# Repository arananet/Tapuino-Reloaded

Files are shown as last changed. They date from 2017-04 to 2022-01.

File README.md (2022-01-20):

# Tapuino-Reloaded

Designed in 2017 By @edu_arana in collaboration with @groovydrifter & @jgilcas. Based on the original schematic design of Peter Edwards.

# Updates

20/01/2021: Uploaded gerbers version 0.42 with the pin8 fixed on HC4050.

20/01/2021: On rev 0.41 There might be a problem with pin 8 on the SD card buffer. If PCB manufacturer does not populate a required via to make pin 8 from the HC4050 to GND, this could produce a problem with SD card detection. If you have a multimeter, try to measure pin 8 from the HC4050 to GND, if you have continuity then the SD Card detection or initialization problem might be elsewhere, if not, to fix this, try to solder pin 8 to pin 2 of the octocoupler (GND). Find the instruction on how to fix this on the GERBERS-NANO directory. Thanks to the user Alleged-Geek for point this out.

12/11/2019: Updated license stuff (I usually not do this but I must start it with this).

12/11/2019: Released version 0.41 using Arduino Nano and 128x32 oled screen.

17/02/2018: Fixed a issue with the 2n2222. Not required anymore.

25/01/2018: New version has born :)

03/06/2017: Add DTR signal on the TTL programming port.

24/05/2017: If your Atmega328 is blank without bootloader you can take advantage by upload the bootloader and firmware directly to the atmega using an ISP like the USBASP. On the ISP folder there is a hex file that include the bootloader plus the firmware (tapuino) for oled screens.

# License

Shield: [][cc-by-sa]

This work is licensed under a [Creative Commons Attribution-ShareAlike 4.0
International License][cc-by-sa].

[][cc-by-sa]

[cc-by-sa]: http://creativecommons.org/licenses/by-sa/4.0/
[cc-by-sa-image]: https://licensebuttons.net/l/by-sa/4.0/88x31.png
[cc-by-sa-shield]: https://img.shields.io/badge/License-CC%20BY--SA%204.0-lightgrey.svg

# Note

This is a work in progress, several testing must be made but it should work as is. I take no responsibiltiy for any damage to any equipment that results from the use of this board. USE AT YOUR OWN RISK!

If you like the project or want to support it, you can buy me a beer or a KO-FI :) 


# Testers

Special thanks to:

@CommodoreSpain
@thejanbeta
@FREEZE64UK

For the awesome review of the Tapuino Reloaded. 

# Version 0.42

Includes a reinforcement on the pin 8 of the 4050 buffer and another OLED position to use 0.96 128x64 oled display. The BOM is the same as the 0.41 version.

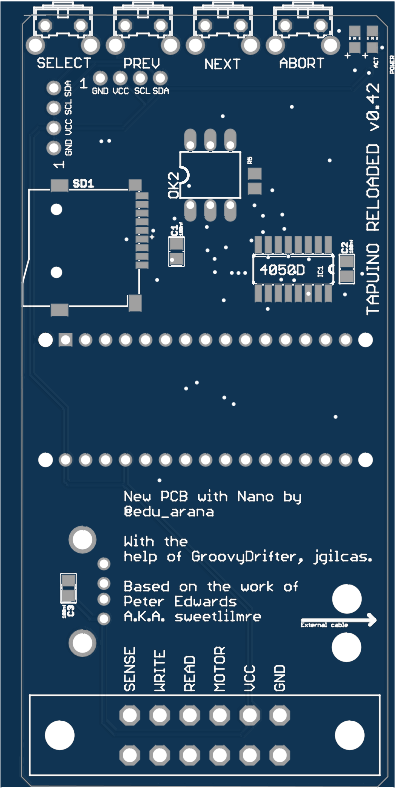
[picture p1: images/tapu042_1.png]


# Version 0.41

This new version of the Tapuino-Reloaded uses a Arduino Nano instead of a PRO MINI like the ealier version. Now is more easy to flash and to update firmware since Ardunino Nano includes a in-build programmer. OLED Screen must be 128x32 and pinouts must be GND VCC SCL SDA (if ends with SDK needs a pullups). Added properly decoupling caps. Manually routed.

# Images

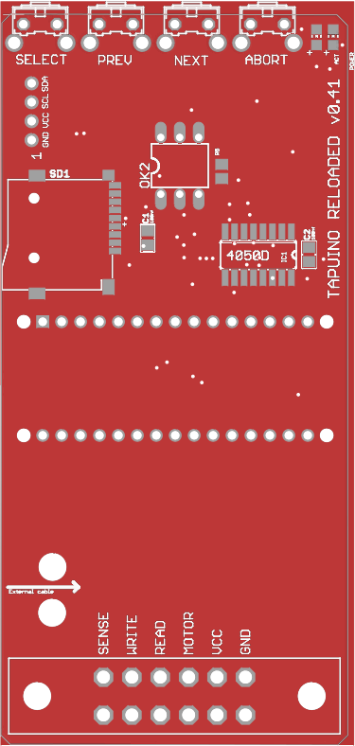
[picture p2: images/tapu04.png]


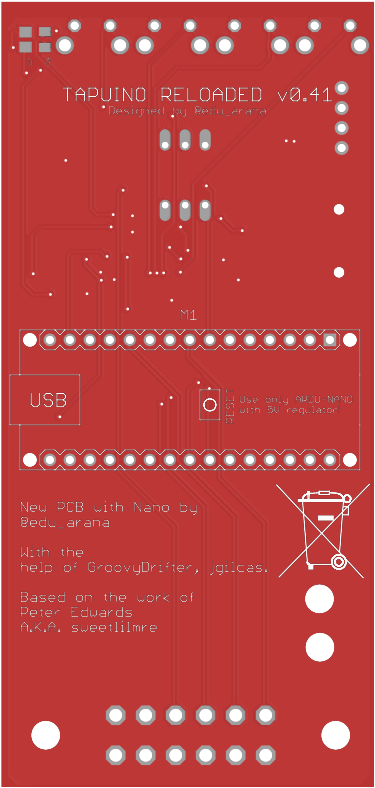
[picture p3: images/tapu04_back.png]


# Bill of materials

| Part | Value | Package |
| --- | --- | --- |
| ABORT1  		| Button | B3F-31XX |
| ACT 		| SMD led | CHIP-LED0805 |
| C1 		| 100nf | 0805 |
| C2 		| 100nf | 0805 |
| CON1 		| CONECTOR_C64_DATASSETTE | CONECTOR_C64_DATASSETTE |
| IC1 		| 4050D (HC4050 or HCT4050) | SO16 |
| M2 		| ARDUINO-NANO | ARDUINO-NANO-3.0 |
| NEXT1 		| Button | B3F-31XX |
| OK2 		| 4N25M | DIL06 |
| OLED 		| Connector for Screen | 128x32 OLED SCREEN |
| POWER 		| SMD led | CHIP-LED0805 |
| PREV1 		| Button | B3F-31XX |
| R5 		| 330 | R0805 |
| R7 		| 1k | R0805 |
| R9 		| 1K | R0805 |
| SD1 		| TF-HOLDER | TF-PULL |
| SELECT1 		| Button | B3F-31XX |

#------------------------------------------------------------------------------------------------------------------------------------

# Version 0.3

This new version include the footprint of the Arduino Pro Mini, so you just have to buy a module with compatible footprint and solder it on the PCB. Some of the components has been changed to a better position and some others has been replaced (please refer to the BOM). Remember, once you solder and flash the Tapuino, you just plug the Tapuino Reloaded on the back of your C64 (Breadbox & C) and that's it. This design also allows to use every type of i2c LCD or OLED Screen, by soldering a 1x4 row pin and taking out the lcd to a better viewable area, for example on computers like the Commodore PET.

# Images

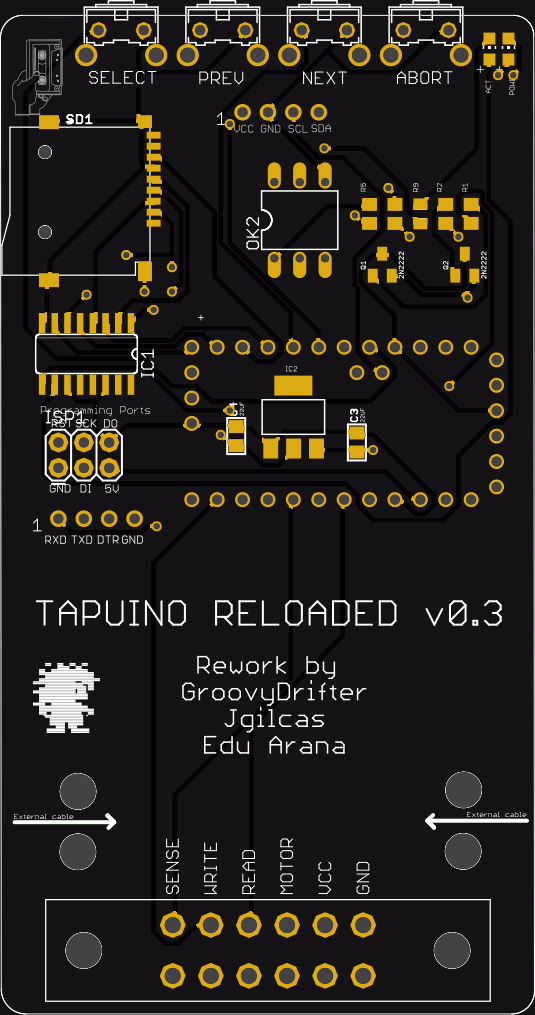
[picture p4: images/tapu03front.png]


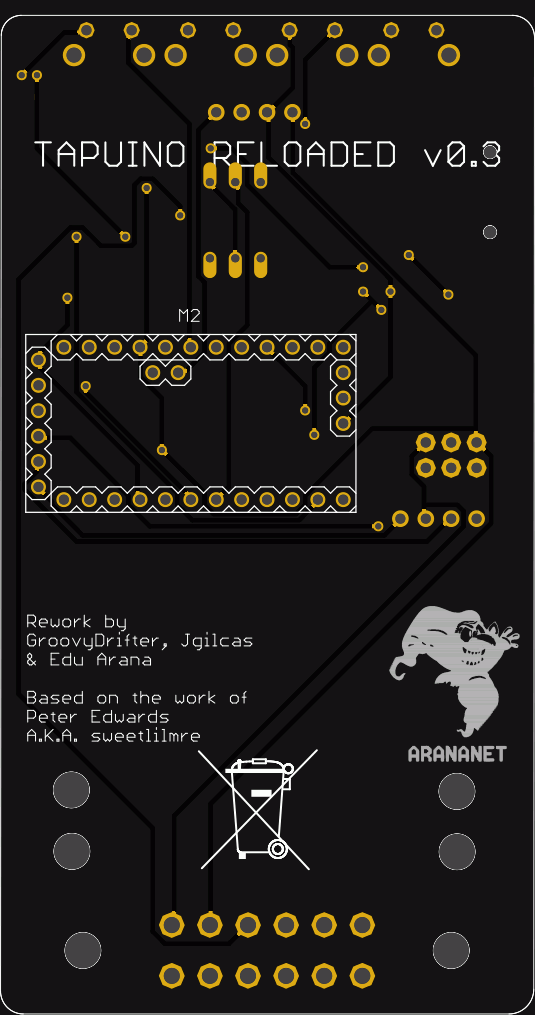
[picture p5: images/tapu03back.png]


# Instructions

The same as 0.2, except that you don't need to apply fuses on the Arduino Pro Mini.

# Bill of materials

| Part | Value | Package |
| --- | --- | --- |
| ABORT1  		| Button | B3F-31XX |
| ACT 		| SMD led | CHIP-LED0805 |
| C3 		| 22UF | 0805 |
| C4 		| 22UF | 0805 |
| CON1 		| CONECTOR_C64_DATASSETTE | CONECTOR_C64_DATASSETTE |
| IC1 		| 4050D | SO16 |
| IC2 		| REG1117 3v3 | SOT223 |
| ISP1 		| AVR_SPI_PRG_6PTH | 2X3 |
| M2 		| ARDUINO-PRO-MINI-3.3V | ARDUINO-PRO-MINI |
| NEXT1 		| Button | B3F-31XX |
| OK2 		| 4N25M | DIL06 |
| OLED 		| Connector for Screen | 1X04_ROUND |
| POWER 		| SMD led | CHIP-LED0805 |
| PREV1 		| Button | B3F-31XX |
| R5 		| 330 | R0805 |
| R7 		| 120 | R0805 |
| R9 		| 1K | R0805 |
| SD1 		| TF-HOLDER | TF-PULL |
| SELECT1 		| Button | B3F-31XX |
| TTL1 		| Connector | 1X04_ROUND |

#--------------------------------------------------------------------------------------------------------------------------------------

# Version 0.2

This new version has completely reworked with smd components. Also change the distribution and connection orientation. Now, you just plug the Tapuino Reloaded on the back of your C64 (Breadbox & C) and that's it. This design also allows to use every type of i2c LCD or OLED Screen, by soldering a 1x4 row pin and taking out the lcd to a better viewable area, for example on computers like the Commodore PET.

# Images

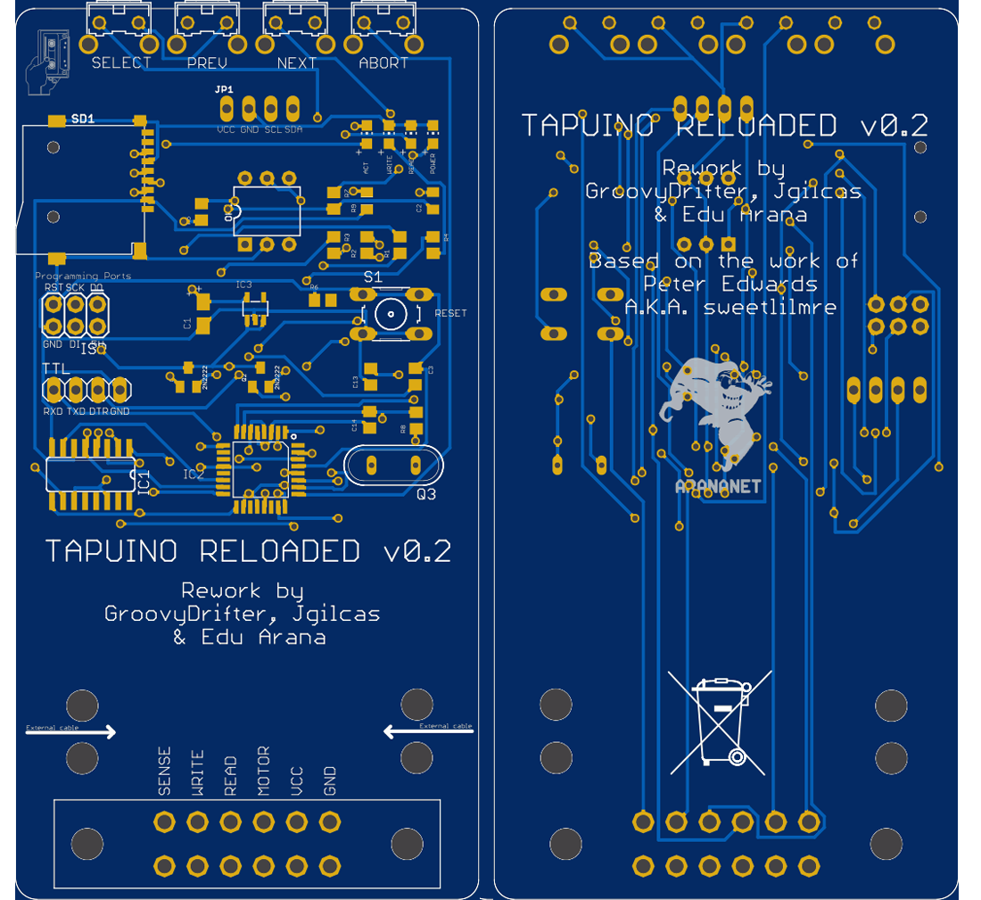
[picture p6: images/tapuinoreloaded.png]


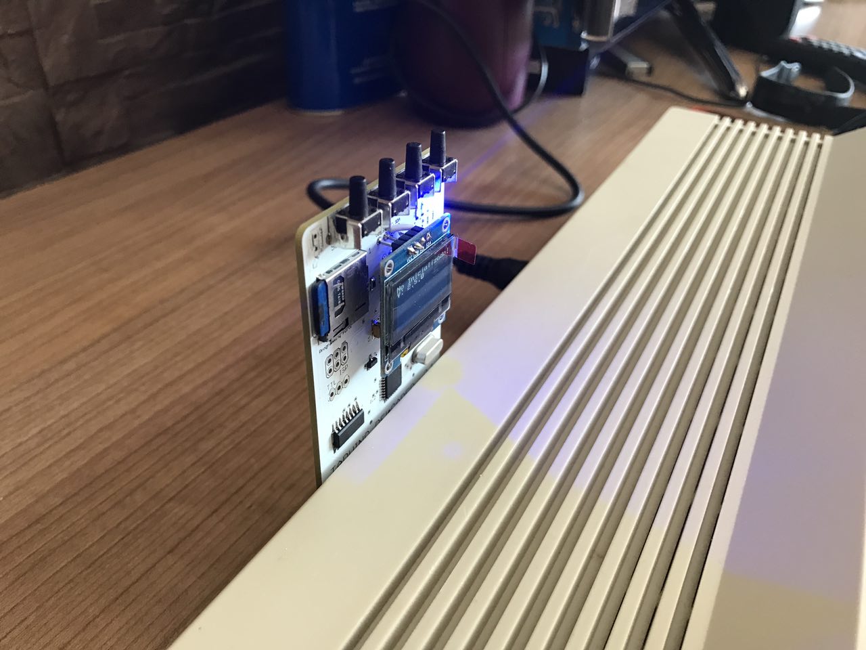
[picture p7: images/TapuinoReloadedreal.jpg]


# Instructions
 
1. Download the official Tapuino code from the Peter Edwards repository https://github.com/sweetlilmre/tapuino 
2. Set the display hardware address on the config-user.h depending on what kind of display have. If does not work, use a i2c scanner in order to get the exact hardware address from the display.
3. Use a serial TTL programmer and the Arduino IDE to upload the code into the ATMEGA.
4. Plug an MicroSD card with all the taps and enjoy the power of the Tapuino!
5. In case we use the hex file to clon and flash many Tapuino devices we need to set the fuses with the avrdude. Fuses are lfuse = 0xff
hfuse = 0xda, efuse = 0x05

# Bill of materials

| Part | Value | Package |
| --- | --- | --- |
| C1 | 10uF/10V | A/3216-18R |
| C2 | 0.1uF | C0805 |
| C3 | 100nF | C0805 |
| C13 | 22p | C0805 |
| C14 | 22p | C0805 |
| CON1 | CONECTOR_C64_DATASSETTE | 2x6 C64_CONNECTOR (pin version)|
| IC1 | 4050D | SO16 |
| IC2 | AVR-ATMEGA328p-TQP32 | QFP32 |
| IC3 | LP298XS | SOT23-5L |
| ISP | AVR_SPI_PRG_6PTH | 2X3 |
| TTL | PINHD_1X03 | 1X03 |
| JP1 | | OLED CONNECTOR |
| ACT | RED | CHIP-LED0805 |
| LED1 | WHITE | CHIP-LED0805 |
| LED2 | BLUE | CHIP-LED0805 |
| POWER | GREEN | CHIP-LED0805 |
| OK1 | 4N25 | DIP06 optocoupler | 
| Q1 | 2N2222 | SOT-23 Transistor | 
| Q2 | 2N2222 | SOT-23 Transistor | 
| Q3 | 16MHZ | QS |
| R1 | 1K | R0805 |
| R2 | 1K | R0805 |
| R3 | 220 | R0805 |
| R4 | 220 | R0805 |
| R5 | 330 | R0805 |
| R6 | 10k | R0805 |
| R7 | 120 | R0805 |
| R8 | 1M | R0805 |
| R9 | 1K | R0805 |
| ABORT1 | PUSH BUTTON | RIGHT ANGLE PUSH BUTTON |
| NEXT1 | PUSH BUTTON | RIGHT ANGLE PUSH BUTTON |
| PREV1 | PUSH BUTTON | RIGHT ANGLE PUSH BUTTON |
| S1 | PUSH BUTTON | PUSH BUTTON |
| SELECT1 | PUSH BUTTON | RIGHT ANGLE PUSH BUTTON |
| SD1 | TF-HOLDER | TF-PULL |

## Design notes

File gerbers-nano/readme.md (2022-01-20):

## Tapuino Reloaded using Arduino Nano.

File description:

tapureloaded_arduinonano.042 last version.

tapureloaded_nano.zip version 0.41.

## Possible fix for 'Card not initialized' on version 0.41

There might be a problem with pin 8 on the SD card buffer. If PCB manufacturer does not populate a required via to make pin 8 from the HC4050 to GND, this could produce a problem with SD card detection. If you have a multimeter, try to measure pin 8 from the HC4050 to GND, if you have continuity then the SD Card detection or initialization problem might be elsewhere, if not, to fix this, try to solder pin 8 to pin 2 of the octocoupler (GND). 

Also do not use CD4050BM it wont work, use HC4050 or HCT4050 instead.

See the next picture for illustration purposes.

Thanks to the user <b>Alleged-Geek<b/> for point this out.

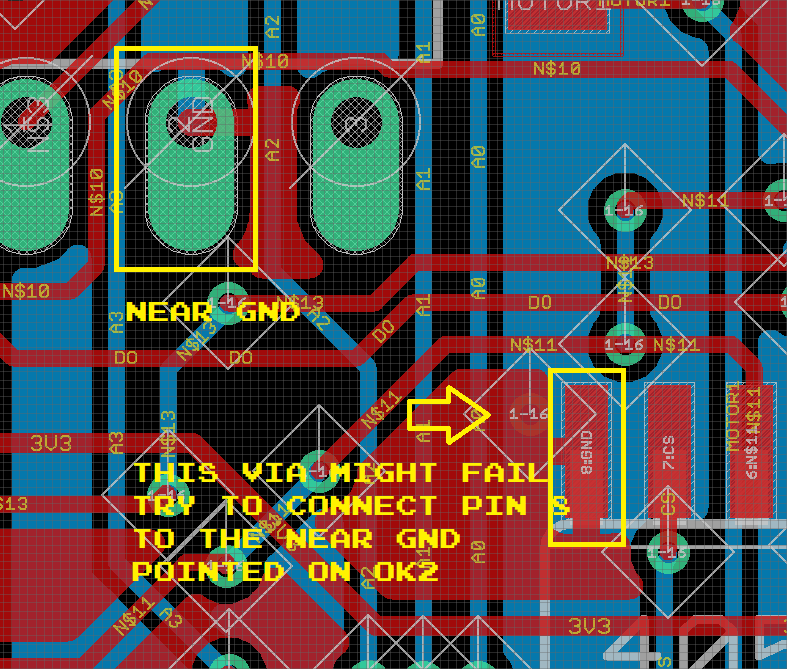
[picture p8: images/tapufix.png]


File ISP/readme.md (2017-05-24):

# Fichero para carga por ISP | File for ISP upload

Puedes utilizar el USB para inyectar directamente el bootloader y firmware del tapuino en el atmega 328.

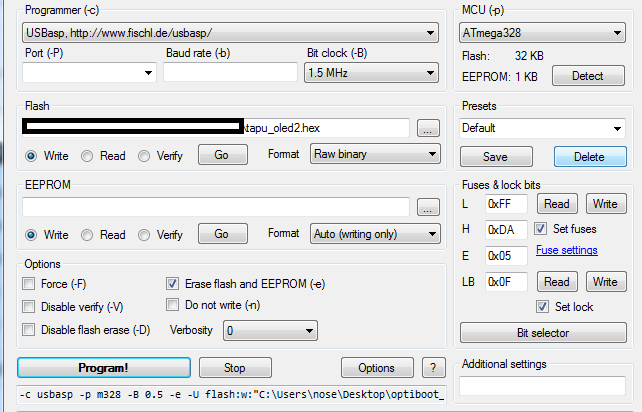
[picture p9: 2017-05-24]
ISP/avrdudess.png

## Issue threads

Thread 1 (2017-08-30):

Recording to tape?

DieKatzchen, 2017-08-30:
It's

DieKatzchen, 2017-08-30:
Sorry, phone glitched out. Is it possible to use this to connect to a datasette device and make new cassettes?

arananet, 2017-08-31:
Nope, you can load the tap files onto the c64 !

TazDevil251, 2020-08-06:
How can I buy one? Thx

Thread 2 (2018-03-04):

oled display

patzik, 2018-03-04:
Maybe not really an issue, but more a question. You say "17/02/2018: Add a screen voltage selector, this is because some chinese oled screen came with the VCC and GND mixed. This can be change on the screen (there are two resistros to swap voltage) but it will more fast to select onboard with two new available solder jumpers."
I still have some pcb's with the 0.2 design and some screens with the swapped vcc/gnd, how can I swap these pins on the screen, which 2 resistors need to be changed?
This was in the tzxduino pcb not the tapuino..

arananet, 2018-03-05:
Hi,On the back of the oled screen there are on the top of the pcb just down to the pins connection, two 0ohm resistors. You need to swap or remove them and put a bridge with solder iron on the path to swap the voltages.I dont remember correctly but for example1  2  3 (2-3 soldered by default)1  2  3 (1-2 soldered by default)And it must be 1  2  3 (1-2 soldered by default)1  2  3 (2-3 soldered by default)Regards,Edu.

  El 5 de marzo de 2018 a las 0:40 patzik <notifications@github.com> escribió:

 Maybe not really an issue, but more a question. You say "17/02/2018: Add a screen voltage selector, this is because some chinese oled screen came with the VCC and GND mixed. This can be change on the screen (there are two resistros to swap voltage) but it will more fast to select onboard with two new available solder jumpers." I still have some pcb's with the 0.2 design and some screens with the swapped vcc/gnd, how can I swap these pins on the screen, which 2 resistors need to be changed?
 —You are receiving this because you are subscribed to this thread.Reply to this email directly, view it on GitHub, or mute the thread.

patzik, 2018-03-06:
I guess I have different screens, there are no 0-Ohm resistors and gnd is connected directly to the ground plane.

I have another question, when I enable the op-amp, there is no sound from the tzxduino, also the led ‘active’ is not working as expected. When placed as indicated on the pcb is does not light up, when placed reversed it lights continuously.
Only thing I’m not sure about is the ‘orientation’ of the 4050D because I don’t see a dot or notch on the ic.
Any suggestions? Could it be the 4050D?

arananet, 2018-03-06:
Do you have the last version of the tzxduino? the old version has the "enable amp" backwards.

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

4050D pin is the top left (note that blue footprint is the bottom layer).

Led pins are marked correctly at least on the last version.

Let me know if you sort out.

Regards,
Edu.

patzik, 2018-03-06:
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
The board I am using is 1.31 and the tzxduino version is 1.9.
Regarding the 4050D orientation, I didn't mean the silkscreen but the actual component (picture included). I just tried turning the component 180 degrees, but this sent me into a wild goose chase, won't bore you with the details but I switched it back to the orientation as in the picture (not 100% sure still if it is ok, but I guess the whole thing wouldn't work if it wasn't)
Can you clarify the usage of the solder jumper on the back and the jumper on the front, do I need to use/set both or are they the same?

arananet, 2018-03-07:
Hi,

4050D is ok on that pic.

Solder jumper on the back is for enable or disable the amp, by the amp i mean by tell tzxduino that "have an existing amp" or not, which include all the electronics of the amplification.

I have deleted the version 1.3.1 from my repository, so I don't remember correctly. But there was a mistake on the silkscreen. With the enable and disable amp. If you 1.31 has a dual jumper in the front, then you have to set the configuration of your oled screen acording to your physical setup.

Example:

Top jumper: Solder VCC to out1 to select VCC on the left connector.
Bottom jumper: Solder GND to out2 to select GND on the left connector.

So the screen connector would be VCC GND SCL SDA

Note: That if your oled screen puts SCK instead of SCL you maybe need pullups resistors in order to make it work. Some oled has already, some others don't

BTW. I see you have put an issue in a wrong repository. This repo is for the TAPUINO not for the TZXDUINO.

Regards,
Edu.

Closed 2018-03-07.

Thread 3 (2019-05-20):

Dead unit?

psurma, 2019-05-20:
I have a Tapuino Reloaded 0.4 which has been sitting idle for some time.  Plugged it in but does nothing on the display, yellow activity light stays lit and red power on the nano at the back.  Seems somewhat dead, any advice?

arananet, 2019-05-20:
Hi

At least with or without SD card should display something on the oled screen.

Can you send a Pic of your tapuino?

Regards
Edu

El 20 de mayo de 2019 13:24:50 GMT-04:00, Pete <notifications@github.com> escribió:
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

--
Enviado desde mi dispositivo Android con K-9 Mail. Por favor, disculpa mi brevedad.

psurma, 2019-05-21:
Hi edu, yea. Toning on display with or without an SD card.

Sent from my iPhone

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

arananet, 2019-05-22:
If you power the Tapuino using  Arduino on the back, does it work?

De: Pete <notifications@github.com>
Enviado el: martes, 21 de mayo de 2019 7:43
Para: arananet/Tapuino-Reloaded <Tapuino-Reloaded@noreply.github.com>
CC: Arananet <info@arananet.net>; Comment <comment@noreply.github.com>
Asunto: Re: [arananet/Tapuino-Reloaded] Dead unit? (#3)

Hi edu, yea. Toning on display with or without an SD card.

Sent from my iPhone

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

—
You are receiving this because you commented.
Reply to this email directly, view it on GitHub <https://github.com/arananet/Tapuino-Reloaded/issues/3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> , or mute the thread <https://github.com/notifications/unsubscribe-auth/ABUJYZHTDWKTN45N4EJGVXTPWODWNANCNFSM4HOD6NJA> .  <https://github.com/notifications/beacon/ABUJYZCEULZYAHJSSUUMR6TPWODWNA5CNFSM4HOD6NJKYY3PNVWWK3TUL52HS4DFVREXG43VMVBW63LNMVXHJKTDN5WW2ZLOORPWSZGODV2Z6TY.gif>

psurma, 2019-05-22:
Hi Edu,

Yes if I plug a USB cable into the Nano, the Power LED is solid on the Nano and the Activity light stays solid on the Tapuino.

Ahhh, ok just tried a spare display that I pulled out of a gotek and that seems to work, so it seems the display died.

No probs, thanks for your help

Cheers
Pete

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

arananet, 2019-05-22:
Is the Oled soldered on the board or is with a female plug?

That’s why I ask for the pics. That could be a “contact” problem.

Do you have oled for spare? I can send you one. (remember me your order number).

Regards,

Edu.

De: Pete <notifications@github.com>
Enviado el: miércoles, 22 de mayo de 2019 9:22
Para: arananet/Tapuino-Reloaded <Tapuino-Reloaded@noreply.github.com>
CC: Arananet <info@arananet.net>; Comment <comment@noreply.github.com>
Asunto: Re: [arananet/Tapuino-Reloaded] Dead unit? (#3)

Hi Edu,

Yes if I plug a USB cable into the Nano, the Power LED is solid on the Nano and the Activity light stays solid on the Tapuino.

Ahhh, ok just tried a spare display that I pulled out of a gotek and that seems to work, so it seems the display died.

No probs, thanks for your help

Cheers
Pete

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

—
You are receiving this because you commented.
Reply to this email directly, view it on GitHub <https://github.com/arananet/Tapuino-Reloaded/issues/3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> , or mute the thread <https://github.com/notifications/unsubscribe-auth/ABUJYZAMSHQ4LDEQ6NALDXLPWTYAFANCNFSM4HOD6NJA> .  <https://github.com/notifications/beacon/ABUJYZFB6UHDNFPWPK23NQ3PWTYAFA5CNFSM4HOD6NJKYY3PNVWWK3TUL52HS4DFVREXG43VMVBW63LNMVXHJKTDN5WW2ZLOORPWSZGODV6EUBY.gif>

psurma, 2019-05-22:
It is plugged in with a female plug (very loose), but the Tapuino is working fine with the spare display and that is also very loose.

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

arananet, 2019-05-22:
Ok. Great then.

Thanks.

Edu.

De: Pete <notifications@github.com>
Enviado el: miércoles, 22 de mayo de 2019 9:26
Para: arananet/Tapuino-Reloaded <Tapuino-Reloaded@noreply.github.com>
CC: Arananet <info@arananet.net>; Comment <comment@noreply.github.com>
Asunto: Re: [arananet/Tapuino-Reloaded] Dead unit? (#3)

It is plugged in with a female plug (very loose), but the Tapuino is working fine with the spare display and that is also very loose.

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

—
You are receiving this because you commented.
Reply to this email directly, view it on GitHub <https://github.com/arananet/Tapuino-Reloaded/issues/3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> , or mute the thread <https://github.com/notifications/unsubscribe-auth/ABUJYZFAIUNRCZEA6KZZT5DPWTYRLANCNFSM4HOD6NJA> .  <https://github.com/notifications/beacon/ABUJYZE6WVZ5A4ZAAB6ROPLPWTYRLA5CNFSM4HOD6NJKYY3PNVWWK3TUL52HS4DFVREXG43VMVBW63LNMVXHJKTDN5WW2ZLOORPWSZGODV6E6RI.gif>

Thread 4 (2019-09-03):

Error on SDCard

LordFennec, 2019-09-03:
Hi, I build the tapuino reloaded 0.3 (last version without 2n2222), but when it starts, it stops on the initialization of the SD. Sometimes it fails and sometimes it freezes. I tried on other micro sd cards which work with the tapuino mini

arananet, 2019-09-04:
Check your solders, looks like something is bridged. Have you use the same buffer? 4050?

LordFennec, 2019-09-04:
I used cd4050bm.... Or 74hc4050d Is better?

arananet, 2019-09-04:
74hct4050d will be better yes.

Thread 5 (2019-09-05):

Tapuino 0.2 Replacement for 2n2222

sajattack, 2019-09-05:
So I guess the 2n2222 was discontinued or something and prices skyrocketed. I have the 0.2 design which looks like still needs it? Can I replace it with another sot-23 transistor? What would you recommend?

sajattack, 2019-09-05:
How's this? https://www.digikey.ca/product-detail/en/diodes-incorporated/MMBT2222A-7-F/MMBT2222A-FDICT-ND/815723

arananet, 2019-09-05:
2n2222 is not discontinued but I just not necessary on new designs. That part will work

Closed 2019-09-05.

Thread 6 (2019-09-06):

No Inicializado Error

sajattack, 2019-09-06:
I'm testing my Tapuino Reloaded v0.2, just by powering it from an arduino, and it says "No Inicializado", with or without an sd card. Is there something special that needs to go on the sd card?

sajattack, 2019-09-06:
Oh, probably the transistors I forgot about.

arananet, 2019-09-06:
It needs to be formatted on fat32 at least.

sajattack, 2019-09-08:
I have one 16GB fat32-formatted micro-sd card and two tapuinos. One of the tapuinos says "No Inicializado" as I mentioned, and the other one just gets stuck on "Inicializando" Do I need like a .lst file or anything on the tapuino? Does it support folders?

arananet, 2019-09-08:
Tapuino works with fat partition. So you don't need any special file. If you get stuck on initialization, it's a hw problem. When the code send a the initialization chain to the SD, this return status and start with the reading. If it get stucked then something keeps from doing that. Check soldering on sd socket. Check continuity on the miso mosi sck pins between the SD and the arduino. I don't know what else you your check. Tapuino 0.2 was one of the first protos.

sajattack, 2019-09-08:
Does the RXD TXD header have debug info?

sajattack, 2019-09-09:
I got one of them working by reprogramming it, and started making comparisons between the working and non-working version. The best clue I got was that "diode drop" on my multimeter between vcc and gnd was 1.5-ish volts on the working one and 1.9ish on the non-working one. Something shorted and drawing too much power? idk.

arananet, 2019-09-09:
Yes that can be. A short or a bad arduino module too. You can debug the arduino via serial on the arduino ide. Connecting the tx and rx using a usb to ttl adapter.

sajattack, 2019-09-09:
baudrate?

sajattack, 2019-09-09:
I couldn't get anything more than echoback out of it, even on the working one, I see on https://github.com/sweetlilmre/tapuino it might be 57600, but even then the serial is behind an ifdef which may or not be defined, and when it is defined, I see no calls to serial_println.

arananet, 2019-09-09:
This is basic arduino debug you need to research yourself.

Closed 2019-09-10.

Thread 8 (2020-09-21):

v0.41 display

chuckcaley, 2020-09-21:
I have made one of these boards but i am having a problem with the display.
My display has the letters of GND VCC SCL SDA. But when i connect it to the board i just get some random dots on 4 lines. If i put in my 128x64 display that reads ok  The letters on that are GND VCC SCK SDA. What do i need to do to get the display with SCL working as that is a 128x32 display?

arananet, 2020-09-21:
This is not an issue... displays with SCK and SDA requires pullups with a 4k7 resistors in order to work. The correct display will be those that has the SCL SDA.

Closed 2020-09-21.

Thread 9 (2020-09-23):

V0.41 board

chuckcaley, 2020-09-23:
I believe this is an issue as i said my display is a GND VCC SCL SDA and it comes up with random dots on the screen no text, screen is an 128x32. I have tried both scl and sck versions of the 128x32 screen and both results are the same. But on my 128x64 screen the text is correct, and the sd card fails to initialize. I am using arduino ide 1.57

arananet, 2020-09-23:
is not an issue, the design works out of the box, specially the oled, now if you also have problem with the inicialization, then is worst and not firmware related, instead hardware (soldering) related. There are like 300 units around the worlds ,with no issues.

You arduino ide is too old too. Try using the last version, and download the firmware from the Peter's repo.

chuckcaley, 2020-09-23:
I've fell foul of the WAVGAT one's before on the uno's. Ok i have got both of the screens to work scl and sck one's, just got to sort the sd card out now. Using 1.8.42 of ide software. I have some stuff that donen't like the new ide so i will keep that on my laptop and keep the newer versions on my desktop.

arananet, 2020-09-23:
sd card is related with the buffer and the spi signals from the arduino, it might be the sd library that you are using.

chuckcaley, 2020-09-23:
Tried various versions of the sd libary, will have another look/go when i havnt got work.

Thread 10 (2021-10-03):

V0.41 Board layout

Alleged-Geek, 2021-10-03:
Firstly I would like to thank you for all your hard work with this fantastic PCB layout. I had a whole lot of fun assembling the PCB.

I did have a wee bit of trouble with the SD card not initilising and I found the problem to be that pin 8 of the 4050 is not actually connected to ground.

All fixed now and I am really enjoying your hard work and effort!

Many thanks!

Alleged-Geek

arananet, 2022-01-20:
Thanks for point this out. I've made a comment on the gerbers-nano directory. https://github.com/arananet/Tapuino-Reloaded/tree/master/gerbers-nano

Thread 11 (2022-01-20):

Issues with a cheap microSDHC cards

Sgw32, 2022-01-20:
Hi,

First of all - thanks for the project.
I think I would better open an issue on tapuino repo, but it is outdated for sure.

Anyway - that's the problem. I have a lot of microSD HC cards for 8-16-32 Gb from Ali and they are working fine on tapecart and patched SD2IEC by me but here it just says "Init Failed v 2.8.0". I've checked code and there is no direct SDHC support(it should send 0xFF for several times, then send a special payload, then proceed to fatfs - that's required for SDHC) , so I think - most of cards are just unsupported, that's a big issue as I think. I have 2 tapuino units and I've checked all parts, but I continue checking if anything is wrong. Anyway there are no solder bridges or something else, everything is just fine, but still does not work.
Which cards are supported, which cards do anyone use?

I unfortunately do not have microSD(not HC/XC!) cards so I can't test it on microSD, however, in most cases microSD support means microSDHC support too - but not works here.

Best regards,
Fedor.

arananet, 2022-01-20:
Hi, that's firmware related, not hardware related. Anyway, I've used standard microsd from 4,8,16,32GB of any brand and they all work. I just format on FAT32 and that's all.

Sgw32, 2022-01-20:
Already connected this pin, however still no progress.
Are your cards SDHC and not SD?

Ill buy a couple of microSD(not HC) cards next week and write if it will work.

Thanks!

arananet, 2022-01-20:
SD >=8GB are SDHC. They also work.

Another thing that can produce a problem is the current Nano version that you have chosen on the Arduino Ide, you must choose (if it appears as an option), Nano Old boot loader.

Sgw32, 2022-01-20:
https://raw.githubusercontent.com/arananet/Tapuino-Reloaded/master/images/TapuinoReloadedreal.jpg

Nano old bootloader selected, firmware is loaded and screen is working. However, look at repo image - it also says init failed. Card inserted.
I do not know issues with FatFS, it works good with SDHC even with a version from 2009(Tested!) however there is no SDHC payload in the code. Such payload is not required as I know on good cards i.e. transcend, sandisk and some others, while ALYNX and other noname brands may require it.. Anyway I fixed such a problem with deleting a reply waiting from sd card, so most of cards just do not answer at detect stage, but still work. I also mean, it should work with all known types of FAT. My cards are however FAT32 with standard partitition.

arananet, 2022-01-20:
I see.

If the problem is related to the partition and not the SD CARD itself, then you can use DISKPART from WINDOWS to make a 2GB partition on the SD and format it to fat32. This works on some retro hardware projects as a "fix".

Sgw32, 2022-01-20:
Thanks. I'll check it today or tomorrow.

Sgw32, 2022-01-23:
Hi. Issue solved - Arduino Nano clones from China have a weak 3V3 regulator. It is needed to add an external one to 3V3 pin(from 5V) AMS/LM1117-3V3 is working.
I recommend you to release the schematic (probably PCB too ... if possible 😃 ) I spent some time probing signals after importing gerbers to Sprint Layout... Your board is a bit different because uses 4050 as a voltage converter instead of voltage dividers/direct driving.

Anyway thanks! :D

arananet, 2022-01-23:
Hi, thanks for the update. Well that's not entirely a tapuino reloaded issue, instead, of the NANO that you are using. On the version that I've on sale on my store, I put the atmega directly on the PCB and a 3v3 regulator to power all the 3v3 signals. Sometimes when a AMS1117-3v3 is used, you just need to add a 22UF capacitor to the 3v3 output to fix the lower output. It is stated on the AMS-1117-3v3 datasheet :)

Thanks for your time.

Closed 2022-01-23.

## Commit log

2017-05-14 Drill holes fixed (for the gerber viewers online)
    [TapuinoReloaded.GTO]
2017-06-03 Add DTR signal a some component aligment.
    [TapuinoReloaded.GBL, TapuinoReloaded.GBO, TapuinoReloaded.GBP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]
2017-09-07 Update README.md
    fixed fuses configuration.
2022-01-20 Delete tapureloaded_arduinonano.042_2022-01-20.zip
    bad gerber
